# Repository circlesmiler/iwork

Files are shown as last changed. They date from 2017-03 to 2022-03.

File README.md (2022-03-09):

# iWork - Work Time Recognizing on Particle Photon
This is a Particle Photon project. The idea is to provide a simple display
and a login and logout button to recognize the start work time end the end
of work.

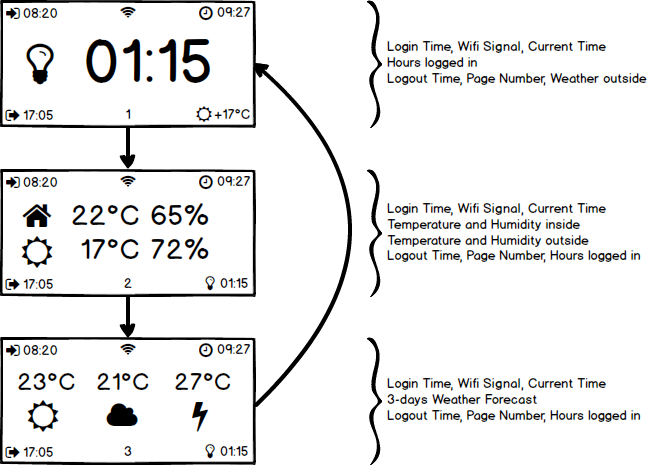
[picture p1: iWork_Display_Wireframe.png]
Wirfeframe Mock Up


On the display, you can see following informations:
* Start of Work (hh:mm)
* End of Work (hh:mm)
* Time at Work (hh:mm)
* Current Time (hh:mm)
* WIFI strength (as Image)
* Outside Temperature (OpenWeather API)

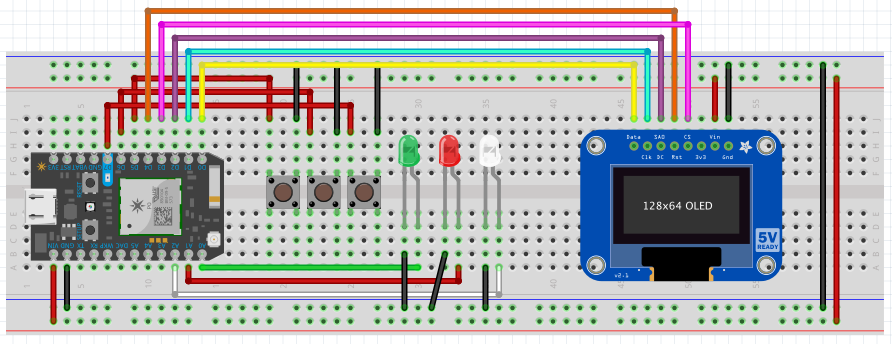
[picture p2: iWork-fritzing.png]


## Login and Logout
It's possible to login and logout due to
* Pressing the login or logout button
  * Publishes an Event _work_state_ with folling data:
    * Start|||01.01.2017 07:00
    * Ende|||01.01.2017 17:00
* Using the IFTTT Location
  * Trigger: Mobile Phone Location (IFTTT app needed on the phone)
  * Action: Particle Publish Event
    * Event == "on_work"
    * Data == %EnteredOrExited%
* Using the IFTTT button widget (on phone)
  * Trigger: Button widget
  * Action: Particle Publish Event
    * Event == "on_work"
    * Data == "entered" or "exited"

For a better usability, I used buttons with integrated LEDs, that can be
controlled separately. So, the *Login Button* glows GREEN, when the user is
currently not logged in. The LED turns of, when the user pressed the
*Login Button*. The *Logout Button* only glows RED, when the user is currently
logged in. Very easy, isn't it? ;-)

<a href="http://www.youtube.com/watch?feature=player_embedded&v=zKBNXiXqFS4" target="_blank">
iWork at work
</a>

## Weather Configuration (City ID)
The temperature shown on the display is provided by the OpenWeather API. To
get the temperature value of your city, you can call the Particle function
_owmCityId_ to set your city id.

See also http://openweathermap.org/help/city_list.txt

## The Mode Button
A click on the **Mode Button** changes the page on the display. A long click on
the **Mode Button** changes to a **setup mode**. Currently the **setup mode** is
only a dummy function. The idea is to UNDO a wrong login or logout due to the
IFTTT actions.

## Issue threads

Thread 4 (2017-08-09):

Add temperature/humidity sensor DHT22

circlesmiler, 2017-08-09:
There are still some PINs on the photon unused, so the idea is to add the DHT22 sensor for getting temperature and humidity data.

Attention: The DHT22 needs a PIN with interrupt support.  Some PINs shares the interrupt line. So We can only use PIN A6 and A7 (see https://docs.particle.io/reference/firmware/photon/#attachinterrupt-)

circlesmiler, 2018-12-23:
Done

Closed 2018-12-23.

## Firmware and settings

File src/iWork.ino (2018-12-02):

// This #include statement was automatically added by the Particle IDE.
#include <clickButton.h>

#include <Adafruit_GFX.h>
#include <Adafruit_SSD1306.h>

#include "DataModel.h"
#include "WeatherModel.h"
#include "Icons.h"
#include "PageOne.h"
#include "PageTwo.h"

// Lib instantiate
volatile bool bMeasureAirFlag = false;		    // flag to indicate we started acquisition

// TIME SYNC CONSTANT
#define ONE_DAY_MILLIS (24 * 60 * 60 * 1000)
unsigned long lastTimeSync = 0;

//PIN PHOTON => PIN OLED
#define OLED_MOSI   D0 //=>D1
#define OLED_CLK    D1 //=>D0
#define OLED_DC     D2 //=>DC
#define OLED_CS     D3 //=>CS
#define OLED_RESET  D4 //=>RST
Adafruit_SSD1306* display = new Adafruit_SSD1306(OLED_MOSI, OLED_CLK, OLED_DC, OLED_RESET, OLED_CS);

#if (SSD1306_LCDHEIGHT != 64)
#error("Height incorrect, please fix Adafruit_SSD1306.h!");
#endif

// PIN LED-Button Constants
#define BTN_LOGIN   D5
#define BTN_LOGOUT  D6
#define BTN_MODE    D7

#define LED_LOGIN   A0
#define LED_LOGOUT  A1
#define LED_MODE    A2

// EEPROM addresses
#define ENTER_ADDR 0
#define EXIT_ADDR 4
#define OWM_CITY_ADDR 8
#define TIME_ZONE_ADDR 12

ClickButton loginButton(BTN_LOGIN, LOW, CLICKBTN_PULLUP);
ClickButton logoutButton(BTN_LOGOUT, LOW, CLICKBTN_PULLUP);
ClickButton modeButton(BTN_MODE, LOW, CLICKBTN_PULLUP);

void blinkModeLED()
{
    Serial.println("Blink LED");
    toggleModeLED();
}

Timer blinkModeLEDTimer(1000, blinkModeLED);

// VARIABLES
DataModel* dataModel = new DataModel(ENTER_ADDR, EXIT_ADDR);
WeatherModel* weatherModel = new WeatherModel(OWM_CITY_ADDR);

PageOne* pageOne = new PageOne(display, dataModel, weatherModel);
PageTwo* pageTwo = new PageTwo(display, dataModel, weatherModel);

#define WEATHER_UPDATE_INTERVAL 3600 // 3600sec = 1h
int lastWeatherUpdate = 0;

// IFTTT EVENT HANDLER
void onWorkHandler(const char *event, const char *data) {
  Serial.printlnf("Event '%s' : '%s'", event, data);
    String dataStr = String(data).trim().toLowerCase();
    if (dataStr.equals("entered")) {
        dataModel->login();
    } else if (dataStr.equals("exited")) {
        dataModel->logout();
    }
}

/*
 * Called on Partice event "hook-response/weather/".
 */
void receiveWeather(const char *event, const char *data) {
  Serial.printlnf("Event '%s' : '%s'", event, data);
  weatherModel->setOutdoorData(data);
}

void receiveIndoorTemp(const char *event, const char *data) {
  Serial.printlnf("Event '%s' : '%s'", event, data);
  float temp = atof(data);
  weatherModel->setIndoorValues(temp,0.0f);
}

/*
 * Particle function for updating the OpenWeather city id.
 * @see http://openweathermap.org/help/city_list.txt
 */
int updateWeatherCityId(String data) {
  int cityId = atoi(data);
  weatherModel->setCityId(cityId);
  Particle.publish("weather", String(weatherModel->getCityId()), PRIVATE);
  return cityId;
}

/*
 * Particle function for updating the time zone.
 */
int updateTimeZone(String data) {
  int tz = atoi(data);
  setTimeZone(tz);
  EEPROM.put(TIME_ZONE_ADDR, tz);
  return tz;
}

int mode = 0;

STARTUP(WiFi.selectAntenna(ANT_AUTO));
// Use SYSTEM_THREAD(ENABLED) for non-blocking WiFi
SYSTEM_THREAD(ENABLED);
// Use SYSTEM_MODE(SEMI_AUTOMATIC) for accessing setup method immediatly
// without wainting for Particle cloud.
SYSTEM_MODE(SEMI_AUTOMATIC);

/*
 * Setup serial via USB (for debugging), display, timezone, buttons,
 * Particle subscriptions and functions and connect to Particle cloud.
 */
void setup()   {
    Serial.begin(9600);

    // Use for debugging over serial USB
    // while(!Serial.isConnected());

    // Init display
    // by default, we'll generate the high voltage from the 3.3v line internally! (neat!)
    display->begin(SSD1306_SWITCHCAPVCC);
    // Rotate display 180° (because it's build in in the other direction)
    display->setRotation(2);
    display->clearDisplay();
    display->drawBitmap(39, 7, drehpunktIcon, 48, 48, WHITE);
    display->display();
    delay(500);
    display->clearDisplay();   // clears the screen and buffer

    // Init timezone from EEPROM
    int timeZone;
    EEPROM.get(TIME_ZONE_ADDR, timeZone);
    if (-12 <= timeZone && timeZone <= 12) {
      setTimeZone(timeZone);
    } else {
      setTimeZone(1);
      EEPROM.put(TIME_ZONE_ADDR, 1);
    }

    // Init buttons
    pinMode(LED_LOGIN, OUTPUT);
    pinMode(LED_LOGOUT, OUTPUT);
    pinMode(LED_MODE, OUTPUT);

    // Init Particle subscriptions and functions
    Particle.subscribe("on_work", onWorkHandler);
    Particle.subscribe("hook-response/weather/", receiveWeather, MY_DEVICES);
    Particle.subscribe("dp_temp", receiveIndoorTemp);
    Particle.function("owmCityId", updateWeatherCityId);
    Particle.function("timeZone", updateTimeZone);

    // Initial blinking stuff to indicate setup is complete
    digitalWrite(LED_LOGIN, HIGH);
    delay(200);
    digitalWrite(LED_LOGIN, LOW);

    digitalWrite(LED_LOGOUT, HIGH);
    delay(200);
    digitalWrite(LED_LOGOUT, LOW);

    digitalWrite(LED_MODE, HIGH);

    // Connect to Particle cloud
    Particle.connect();
}

int page = 0;
// PAINT STUFF IN LOOP
void loop() {
  checkButtonState();

  // Load weather data
  if (Particle.connected() && (lastWeatherUpdate + WEATHER_UPDATE_INTERVAL) < Time.now()) {
      bool success = Particle.publish("weather", String(weatherModel->getCityId()), PRIVATE);
      if (success) {
        lastWeatherUpdate = Time.now();
        Serial.println("Weather Event published.");
      }
  }

  display->clearDisplay();   // clears the screen and buffer

  if (!Time.isValid()) {
    Serial.println("Time is not synchronized!");

    display->setTextSize(1);
    display->setTextColor(WHITE);
    display->setTextWrap(false);
    display->setCursor(10,0);
    display->print("Time invalid...");
    display->display();
    waitFor(Time.isValid, 60000);
    return;
  }

  updateLoginLED();
  updateLogoutLED();

  printPageNumber();
  if (page == 0) {
    pageOne->updateDisplay();
  } else if (page == 1) {
    pageTwo->updateDisplay();
  }

  display->display();
}

void checkButtonState() {
  performLoginButton();
  performLogoutButton();
  performModeButton();
}

void performLoginButton() {
  loginButton.Update();
  // Save click codes in LEDfunction, as click codes are reset at next Update()
  int function = 0;
  if(loginButton.clicks != 0) function = loginButton.clicks;

  if(function == 1) {
  Serial.println("Login button clicked.");
    if (mode == 0) {
      dataModel->login();
    }
  }
}

void performLogoutButton() {
  logoutButton.Update();
  // Save click codes in LEDfunction, as click codes are reset at next Update()
  int function = 0;
  if(logoutButton.clicks != 0) function = logoutButton.clicks;

  if(function == 1) {
    Serial.println("Logout button clicked.");
    if (mode == 0) {
      dataModel->logout();
    }
  }
}

void performModeButton() {
  modeButton.Update();
  // Save click codes in LEDfunction, as click codes are reset at next Update()
  int function = 0;
  if(modeButton.clicks != 0) function = modeButton.clicks;

  if(function == 1) {
      Serial.println("SINGLE click");
      if (mode == 0) {
          Serial.println("Change Page");
          // Normaler Modus > Seite weiterschalten
          page = (page + 1) % 2;
      }
  }
  if(function == -1) {
      Serial.println("SINGLE LONG click");
      if (mode == 0) {
          Serial.println("Edit Mode");
          mode = 1;
          blinkModeLEDTimer.start();
      } else if (mode == 1) {
          Serial.println("Normal Mode");
          mode = 0;
          blinkModeLEDTimer.stop();
          setModeLED(true);
      }
  }
}

void updateLoginLED() {
    digitalWrite(LED_LOGIN, !dataModel->atWork());
}

void updateLogoutLED() {
    digitalWrite(LED_LOGOUT, dataModel->atWork());
}

void printPageNumber() {
    display->setTextSize(1);
    display->setTextColor(WHITE);
    display->setTextWrap(false);
    display->setCursor(60,56);

    display->print(page + 1);
}

/*
* HELPER METHODS
*/
void toggleModeLED() {
    digitalWrite(LED_MODE, !digitalRead(LED_MODE));
}

void setModeLED(bool isOn) {
    digitalWrite(LED_MODE, isOn);
}

void setTimeZone(int timeZone) {
  Serial.printlnf("Time zone set to %i", timeZone);
  Time.zone(timeZone);
}

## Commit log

2017-03-10 Fritzing + Library Dependicies
    [iWork.fzz]
2017-03-11 Login/Logout Button implemented + new Fritzing file
    [iWork.fzz]
2017-03-12 Bugfixes: void atWork(), updateLEDs
    [iWork.ino]
2017-08-09 Added balsamiq wireframe files
2017-08-21 Add temparature sensor and second display page for temperature value.
2022-03-09 Add wirfeframe to readme.md
